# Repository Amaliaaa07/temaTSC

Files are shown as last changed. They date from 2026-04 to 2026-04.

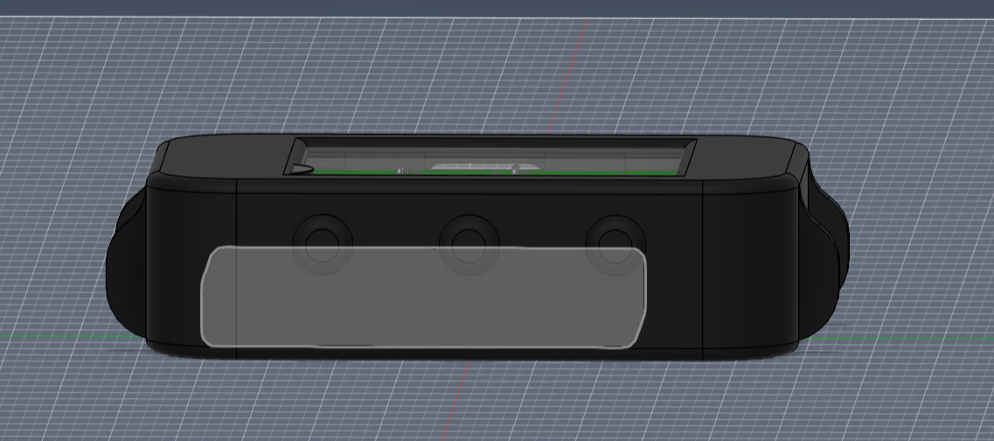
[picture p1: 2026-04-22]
Images/Screenshot 2026-04-22 074130.png

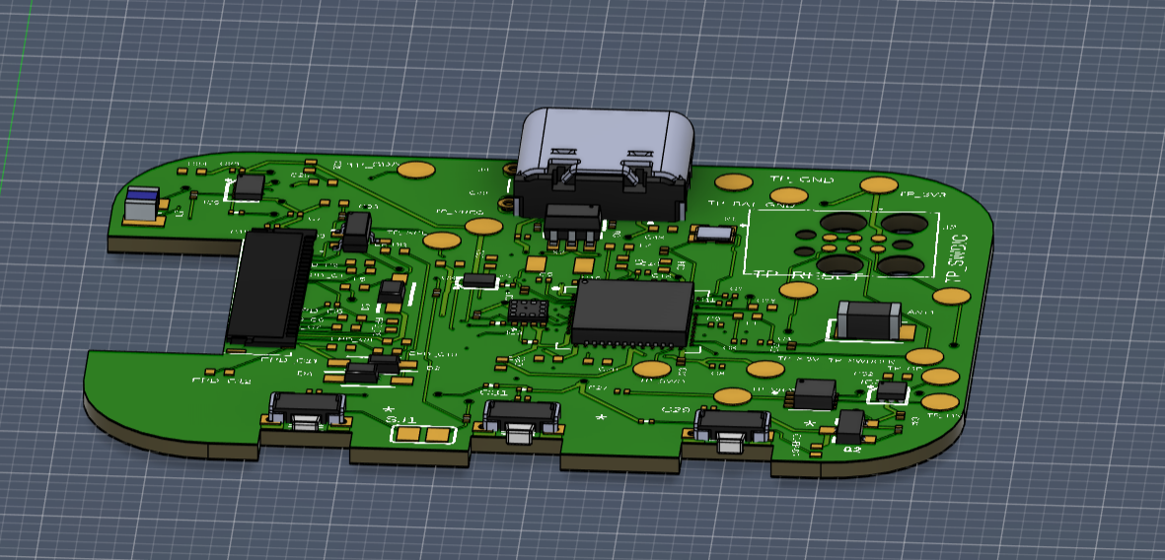
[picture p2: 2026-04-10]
Images/Screenshot 2026-04-10 213231.png

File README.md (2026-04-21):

# temaTSC
smartwatch


## BOM (Bill of Materials)

| Referință | Componentă | Descriere | Cantitate | Link JLC | Datasheet |
|---|---|---|---|---|---|
| U1 | MCU | nRF52840 | 1 | [JLC](https://jlcpcb.com/partdetail/NordicSemiconductor-nRF52840_QIAA/C190794) | [Datasheet](https://4donline.ihs.com/images/VipMasterIC/IC/NRSA/NRSA-S-A0021008244/NRSA-S-A0021008244-1.pdf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)  |
| IC1 | LiPo Charger | BQ25180YBGR | 1 | [JLC](https://componentsearchengine.com/prices/BQ25180YBGR?manufacturer=Texas%20Instruments) | [Datasheet](https://www.ti.com/lit/ds/symlink/bq25180.pdf) |
| IC2 | Haptic Driver | DRV2605YZFR | 1 | [JLC](https://componentsearchengine.com/prices/DRV2605YZFR?manufacturer=Texas%20Instruments) | [Datasheet](https://www.ti.com/lit/ds/symlink/drv2605.pdf) |
| IC3 | IMU | BMA423 | 1 | [JLC](https://componentsearchengine.com/prices/BMA423?manufacturer=BOSCH) | [Datasheet](https://4donline.ihs.com/images/VipMasterIC/IC/BSCH/BSCH-S-A0007921771/BSCH-S-A0010021471-1.pdf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) |
| IC9 | DC/DC Converter | RT6160AWSC | 1 | [JLC](https://componentsearchengine.com/prices/RT6160AWSC?manufacturer=RICHTEK) | [Datasheet](https://4donline.ihs.com/images/VipMasterIC/IC/RHTK/RHTK-S-A0025617216/RHTK-S-A0025617221-1.pdf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) |
| U3 | Fuel Gauge | MAX17048G+T10 | 1 | [JLC](https://componentsearchengine.com/prices/MAX17048G%2BT10?manufacturer=Analog%20Devices) | [Datasheet](https://4donline.ihs.com/images/VipMasterIC/IC/RHTK/RHTK-S-A0025617216/RHTK-S-A0025617221-1.pdf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) |
| D3 | ESD Protection  | USBLC6-2SC6Y | 1 | [JLC](https://componentsearchengine.com/prices/USBLC6-2SC6Y?manufacturer=STMicroelectronics) | [Datasheet](https://www.analog.com/media/en/technical-documentation/data-sheets/MAX17048-MAX17049.pdf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) |
| J4 | USB-C Connector | KH-TYPE-C-16P | 1 | [JLC](https://www.snapeda.com/parts/KH-TYPE-C-16P/kinghelm/view-part/?ref=search&t=KH-TYPE-C-16P&ab_test_case=b) | [Datasheet](https://www.snapeda.com/parts/KH-TYPE-C-16P/kinghelm/datasheet/) |
| J1 | E-Paper Connector | 503480-2400E | 1 | [JLC](https://componentsearchengine.com/prices/5034802400?manufacturer=Molex) | [Datasheet](https://4donline.ihs.com/images/VipMasterIC/IC/MOLE/MOLE-S-A0003522481/MOLE-S-A0010982248-1.pdf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) |
| ANT1 | Antena BLE | 2450AT18B100E | 1 | [JLC](https://componentsearchengine.com/prices/2450AT18B100E?manufacturer=JOHANSON%20TECHNOLOGY) | [Datasheet](https://www.johansontechnology.com/docs/1187/2450AT18B100_X8XXogU.pdf) |
| X1 | Crystal 32MHz | SMD 2016 | 1 | [JLC](https://componentsearchengine.com/prices/SMD2016B050TF?manufacturer=Yageo%20Group) | [Datasheet](https://4donline.ihs.com/images/VipMasterIC/IC/YAGO/YAGO-S-A0024580626/YAGO-S-A0024591343-1.pdf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) |
| X2 | Crystal 32.768kHz | SMD 2016 | 1 | [JLC](https://componentsearchengine.com/prices/SMD2016B050TF?manufacturer=Yageo%20Group) | [Datasheet](https://4donline.ihs.com/images/VipMasterIC/IC/YAGO/YAGO-S-A0024580626/YAGO-S-A0024591343-1.pdf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) |
| SW1-3 | Buton tactil | EVP-AKE31A | 3 | [JLC](https://componentsearchengine.com/prices/EVP-AKE31A?manufacturer=Panasonic) | [Datasheet](https://industrial.panasonic.com/cdbs/www-data/pdf/ATK0000/ATK0000C434.pdf) |
| J2 | SWD Connector | TC2030-IDC | 1 | [JLC](https://componentsearchengine.com/prices/TC2030-IDC?manufacturer=Tag%20Connect) | [Datasheet](https://4donline.ihs.com/images/VipMasterIC/IC/TGCN/TGCN-S-A0008988129/TGCN-S-A0008988129-1.pdf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) |
| Q2 | MOSFET P-ch | DMG2305UX-7 | 1 | [JLC](https://componentsearchengine.com/prices/DMG2305UX-7?manufacturer=Diodes%20Incorporated) | [Datasheet](https://4donline.ihs.com/images/VipMasterIC/IC/DIOD/DIOD-S-A0013043571/DIOD-S-A0013120650-1.pdf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) |
| Q3 | MOSFET N-ch | SI1308EDL-T1-GE3 | 1 | [JLC](https://componentsearchengine.com/prices/Si1308EDL-T1-GE3?manufacturer=Vishay) | [Datasheet](https://4donline.ihs.com/images/VipMasterIC/IC/VISH/VISH-S-A0000692786/VISH-S-A0000692786-1.pdf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) |
| D2, D4, D5  | Dioda Schottky  | MBR0530 | 3 | [JLC](https://componentsearchengine.com/prices/MBR0530?manufacturer=MCC) | [Datasheet](https://4donline.ihs.com/images/VipMasterIC/IC/MCCC/MCCCS04194/MCCCS04194-1.pdf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) |
| L1 | Inductanta 0.47µH | FTC252012SR47MBCA | 1 | [JLC](https://jlcpcb.com/partdetail/6763488-FTC252012SR47MBCA/C5832368) |
| L2 | Inductanta 15nH | RF matching 0201 | 1 | [JLC](https://jlcpcb.com/partdetail/Sunlord-SDCL0201C15NJTDF/C389547) | - |
| L3 | Inductanta 3.9nH | RF matching 0201 | 1 | [JLC](https://jlcpcb.com/partdetail/Sunlord-SDCL0201C3N9STDF/C389544) | - |
| L5 | Inductanta 68µH | EPD driver SMD | 1 | [JLC](https://jlcpcb.com/partdetail/Sumida-CDMC4D28NP680MC/C408336) | - |
| L7 | Inductanta 10µH | DC/DC SMD | 1 | [JLC](https://jlcpcb.com/partdetail/Sunlord-MWSA0402S100MT/C408352) | - |
| C* | Condensatoare | 100nF decuplare 0201 | multiple  | [JLC](https://jlcpcb.com/partdetail/Samsung-CL03B104KO3NNNC/C15195) | - |
| C* | Condensatoare | >100nF bulk 0402 | multiple  | [JLC](https://jlcpcb.com/partdetail/Samsung-CL05A475KP5NRNC/C25771) | - |
| R* | Rezistente | Diverse valori 0201 | multiple  | [JLC](https://jlcpcb.com/partdetail/UNI-ROYAL-0201WAF1001T5E/C17513) | - |

## Descrierea funcționalității hardware

### Microcontroller — nRF52840

Inima dispozitivului este **Nordic nRF52840**, un SoC (System on Chip) cu procesor ARM Cortex-M4 la 64 MHz, cu unitate FPU, 1 MB Flash, 256 KB RAM și radio Bluetooth 5.0 integrat. Chipul operează la 3.3V și gestionează toate perifericele prin interfețele SPI, I2C și GPIO.

### Alimentare

Lanțul de alimentare funcționează astfel:
- **USB-C (KH-TYPE-C-16P)** furnizează VBUS (5V) prin conectorul de încărcare
- **USBLC6-2SC6Y** protejează liniile D+/D- împotriva descărcărilor electrostatice (ESD)
- **BQ25180YBGR** este charger-ul LiPo care încarcă bateria de 3.7V și comunică cu MCU-ul prin I2C pentru a raporta starea încărcării. Curentul maxim de încărcare este de 350mA.
- **MAX17048G+T10** este fuel gauge-ul care măsoară tensiunea bateriei și estimează starea de încărcare (SoC) prin algoritmul ModelGauge, comunicând prin I2C. Generează o întrerupere ALERT când bateria scade sub un prag configurat.
- **RT6160AWSC** este un convertor DC/DC boost care generează tensiunea de 3.3V necesară MCU-ului și perifericelor din tensiunea bateriei. Frecvența de comutare este de 1.5MHz, folosind inductanța L7 de 10µH.

### Display E-Paper

Display-ul e-paper se conectează prin conectorul FFC **503480-2400** (24 pini). Interfața de comunicație este **SPI** (MOSI, SCK) împreună cu semnale de control GPIO:
- **EPD_CS** — chip select
- **EPD_DC** — selectare mod Data/Command
- **EPD_RST** — reset display
- **EPD_BUSY** — semnal de ocupat (MCU-ul așteaptă să devină LOW înainte de a trimite date noi)

Circuitul de drive al display-ului conține diode Schottky MBR0530, MOSFET-uri și inductanța L5 (68µH) pentru generarea tensiunilor ridicate necesare panoului e-paper (PREVGH pozitiv, PREVGL negativ). Marele avantaj al display-ului e-paper este consumul zero în standby — imaginea rămâne afișată fără alimentare (display bistabil).

### IMU — BMA421

Senzorul de mișcare **BMA421** de la Bosch este un accelerometru 3-axis cu consum ultra-redus, folosit pentru:
- Detectarea pașilor (pedometru integrat în hardware)
- Recunoașterea activității (mers, alergat, stat)
- Detectarea orientării dispozitivului
- Wake-up la mișcare (trezirea MCU-ului din sleep)

Comunică cu MCU-ul prin **I2C** la adresa 0x18 sau 0x19 (selectabilă prin pinul SDO). Generează întreruperi pe liniile **INT1** și **INT2** pentru a trezi MCU-ul la detectarea unor evenimente, fără a consuma energie în modul standby. Tensiunea de alimentare este 3.3V (VDDIO și VDD).

### Driver Haptic — DRV2605YZFR

**DRV2605YZFR** de la Texas Instruments este un driver pentru actuatoare haptice (LRA/ERM) cu bibliotecă internă de 123 de efecte de vibrație stocate în ROM. Comunică prin **I2C** la adresa 0x5A și este activat de MCU prin semnalul **HAPTIC_EN** (GPIO). Oferă feedback tactil utilizatorului la interacțiunile cu interfața (notificări, confirmare butoane etc.).

### Conectivitate BLE

Radio-ul BLE integrat în nRF52840 operează la 2.4GHz și suportă Bluetooth 5.0 cu rate de date de 1Mbps (LE 1M PHY) și 2Mbps (LE 2M PHY). Este conectat la antena **2450AT18B100E** de la Johanson Technology printr-o rețea de matching RF compusă din L2 (15nH), L3 (3.9nH) și condensatoare de 1pF. Antena este plasată la exteriorul PCB-ului, iar zona de sub antenă este decupată complet (fără cupru și fără trasee) pentru a nu degrada performanța RF.

### Butoane

Trei butoane tactile **EVP-AKE31A** de la Panasonic (SW_UP, SW_DN, SW_ENT) sunt conectate la GPIO-urile MCU-ului cu rezistențe de pull-up de 10kΩ. La apăsare, pinul GPIO este tras la GND. Butoanele sunt plasate pe marginea PCB-ului, aliniate cu orificiile fizice din carcasă.

### Debug SWD

Interfața de programare și depanare **SWD** este expusă prin conectorul **TC2030-IDC** (Tag-Connect 6-pin, fără găuri). Semnalele disponibile sunt SWDIO, SWDCLK, SWO (trace), RESET, 3.3V și GND. Toate sunt marcate pe silkscreen cu test pad-uri dedicate.

### Oscilatoare

- **Crystal 32 MHz** — oscilator principal pentru MCU și radio BLE, cu condensatoare de sarcină de 12pF. Conectat pe pinii dedicați P0.00/XL1 și P0.01/XL2.
- **Crystal 32.768 kHz** — oscilator pentru RTC (Real Time Clock), cu condensatoare de 12pF. Conectat pe pinii dedicați XC1 și XC2. Permite timekeeping precis în modul low power.

---

## Calcul consum de energie

| Componentă | Curent tipic | Mod |
|---|---|-----|
| nRF52840 | 4.8 mA | Activ CPU |
| nRF52840 | 0.4 µA | Deep sleep |
| nRF52840 | 5.3 mA | BLE advertising |
| BMA421 | 150 µA | Normal |
| BMA421 | 2 µA | Low power |
| DRV2605 | 9 mA | Activ |
| DRV2605 | 40 µA | Standby |
| MAX17048 | 23 µA | Activ |
| RT6160AWSC | ~50 µA | Quiescent |
| Display e-paper | ~26 mA | Refresh |
| Display e-paper | 0 mA | Standby (bistabil) |

**Estimare autonomie:** Cu o baterie LiPo de 200mAh, în modul normal de utilizare (MCU în sleep majoritatea timpului, refresh display de câteva ori pe zi, BLE advertising periodic), curentul mediu estimat este de aproximativ 1-2mA, rezultând o autonomie de **4-8 zile**.

## Pinii nRF52840 utilizați

| Pin nRF52840 | Semnal | Componentă | Interfață | Motiv |
|---|---|---|---|---|
| P0.00/XL1 | XL1 | Crystal 32MHz | XTAL | Pin dedicat oscilator principal |
| P0.01/XL2 | XL2 | Crystal 32MHz | XTAL | Pin dedicat oscilator principal |
| XC1, XC2 | - | Crystal 32.768kHz | XTAL | Pini RTC dedicați |
| P0.04 | EPD_CS | E-Paper | SPI CS | Chip select display |
| P0.05 | EPD_DC | E-Paper | GPIO | Data/Command select |
| P0.06 | MOSI | E-Paper | SPI | Date SPI |
| P0.07 | SCK | E-Paper | SPI | Clock SPI |
| P0.08 | EPD_RST | E-Paper | GPIO | Reset display |
| P0.09 | EPD_BUSY | E-Paper | GPIO | Busy signal display |
| P0.13 | D- | USB-C | USB | Linie date USB |
| P0.14 | D+ | USB-C | USB | Linie date USB |
| P0.25 | SDA | I2C bus | I2C | Date I2C (IMU, Haptic, Charger, FuelGauge) |
| P0.26 | SCL | I2C bus | I2C | Clock I2C |
| P0.27 | PMIC_INT | BQ25180 | GPIO | Întrerupere charger |
| P0.28 | ALERT | MAX17048 | GPIO | Alertă fuel gauge |
| P1.01 | HAPTIC_EN | DRV2605 | GPIO | Enable driver haptic |
| P1.02 | IMU_INT1 | BMA421 | GPIO | Întrerupere IMU 1 |
| P1.03 | IMU_INT2 | BMA421 | GPIO | Întrerupere IMU 2 |
| P1.04 | SW_UP | Buton UP | GPIO | Buton sus |
| P1.05 | SW_DN | Buton DOWN | GPIO | Buton jos |
| P1.06 | SW_ENT | Buton ENTER | GPIO | Buton enter |
| P0.18/RESET | RESET | SWD | SWD | Reset MCU |
| SWDCLK | SWDCLK | TC2030-IDC | SWD | Clock debug |
| SWDIO | SWDIO | TC2030-IDC | SWD | Date debug |
| P0.22 | SWO | TC2030-IDC | SWD | Trace output |
| ANT | RF | Antenă BLE | RF | Pin antenă dedicat |
| VBUS | VBUS | USB-C | Power | Detecție VBUS |

---

## Design log

### Probleme întâmpinate și decizii luate

**Erori Overlap (12) — Aprobate**: Cele 12 erori de overlap 
sunt de trei tipuri:

**Via-Smd Overlap (2)**: Via-uri care se suprapun ușor 
  cu pad-uri SMD în zone aglomerate ale PCB-ului. Mutarea 
  acestora ar compromite rutarea semnalelor din zonă.

**Solid Polygon Shape-Pad Overlap (2)**: Pad-ul 
  termal al unui circuit integrat se suprapune ușor 
  cu conturul (courtyard) componentei vecine. 
  Suprapunerea este minimă și nu afectează 
  funcționalitatea electrică sau asamblarea, 
  deoarece componentele nu se suprapun fizic.

**Smd-Via Overlap (6)**: Via-uri plasate în apropierea 
  pad-urilor SMD în zone aglomerate ale PCB-ului. Acestea 
  sunt necesare pentru rutarea semnalelor și nu pot fi 
  mutate fără a compromite rutarea generală. Suprapunerea 
  este minimă și nu afectează funcționalitatea electrică 
  sau procesul de fabricație.

**Modelele 3D**
Componentele mici (rezistențe 0201, condensatoare 0201/0402) nu au modele 3D individuale asociate și folosesc modelul generic din Fusion 360. Componentele principale (nRF52840, BQ25180, conectorul USB-C, butoanele, cristalele) au modele 3D reale asociate.

---

## Imagini

Randările PCB-ului și ale dispozitivului complet se găsesc în folderul `/Images`.

---

## Licență

Acest proiect este licențiat sub licența **Apache 2.0**. Vezi fișierul [LICENSE](LICENSE) pentru detalii.

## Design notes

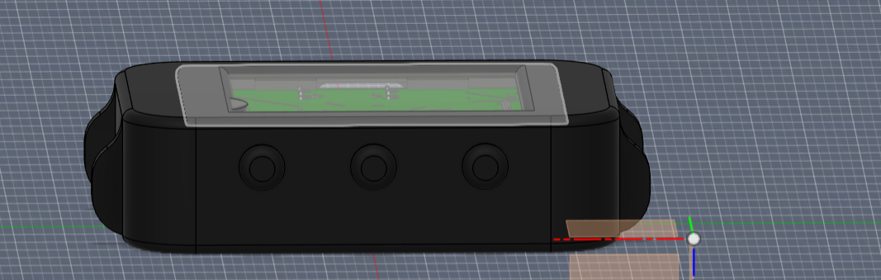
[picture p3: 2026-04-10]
Images/Screenshot 2026-04-10 212922.png

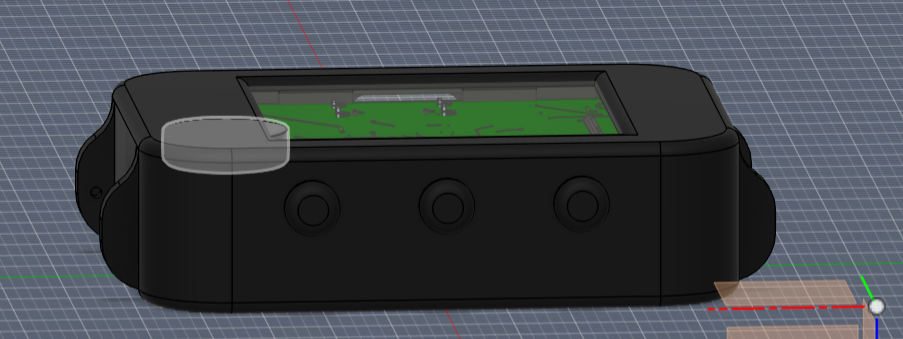
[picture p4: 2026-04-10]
Images/Screenshot 2026-04-10 212859.png

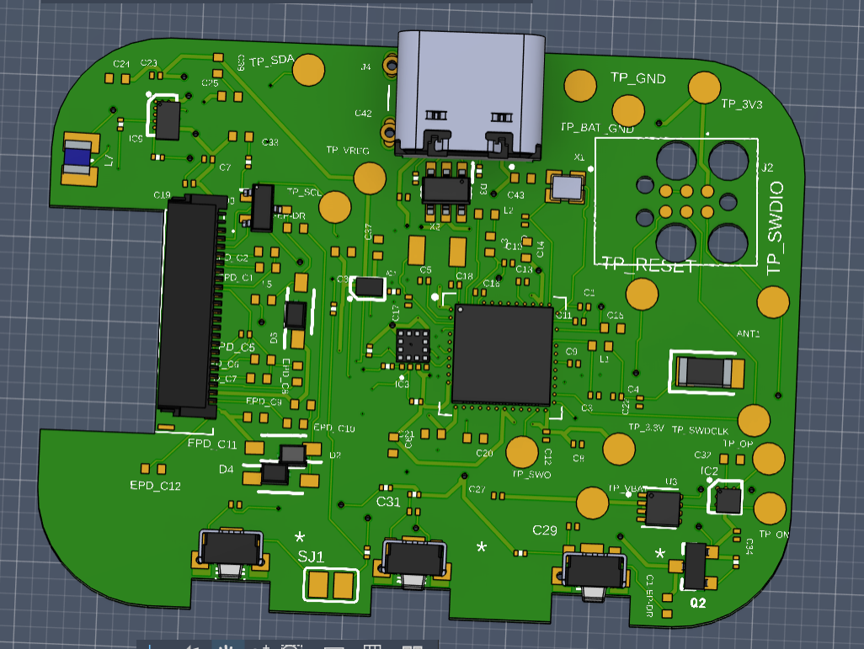
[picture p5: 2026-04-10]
Images/Screenshot 2026-04-10 213246.png

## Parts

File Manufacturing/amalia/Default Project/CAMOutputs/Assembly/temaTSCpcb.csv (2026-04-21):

Qty | Value | Device | Package | Parts | Description | ARROW_PART_NUMBER | ARROW_PRICE-STOCK | AVAILABILITY | CHECK_PRICES | COPYRIGHT | DESCRIPTION | DIGI-KEY_PART_NUMBER_1 | DIGI-KEY_PART_NUMBER_2 | DIGI-KEY_PART_NUMBER_3 | HEIGHT | JLCPCB | MANUFACTURER_NAME | MANUFACTURER_PART_NUMBER | MF | MOUSER_PART_NUMBER | MOUSER_PRICE-STOCK | MP | PACKAGE | POPULARITY | PRICE | PROD_ID | PURCHASE-URL | SNAPEDA_LINK | TP_SIGNAL_NAME | VALUE
1 |  | ESP32_C6_LIBRARY_7_JUMPER_SJ | ESP32_C6_LIBRARY_7_JUMPER_SJ | SJ1 | SMD solder JUMPER |  |  |  |  |  |  |  |  |  |  |  |  |  |  |  |  |  |  | 3
3 | 0 | ERA-1AEB3401C_CPF0201D7K68C1 | ERA-1AEB3401C_0201 | R2, R3, R4 | 7.68k 0201 Thin Film Surface Mount Fixed Resistor +/-0.5% 0.031W CPF0201D7K68C1
2 | 0.1uF | GRM011R60J152KE01L_1_GRM011R60J152KE01L | GRM011R60J152KE01L_1_0201 | C26, C34 | Check availability
2 | 0.1uF | NORDIC_NRF_3_CAPACITOR_0201_L | NORDIC_NRF_3_RESC0201_L | C23, C42 | Generic chip capacitor
1 | 0.1uF/50V | NORDIC_NRF_3_CAPACITOR_0201_L | NORDIC_NRF_3_RESC0201_L | EPD_C5 | Generic chip capacitor
1 | 0.47 | ERA-1AEB3401C_CPF0201D7K68C1 | ERA-1AEB3401C_0201 | R1_EP_DR | 7.68k 0201 Thin Film Surface Mount Fixed Resistor +/-0.5% 0.031W CPF0201D7K68C1
1 | 1.0uF | NORDIC_NRF_3_CAPACITOR_0402_L | NORDIC_NRF_3_RESC0402_L | C15 | Generic chip capacitor
5 | 100nF | NORDIC_NRF_3_CAPACITOR_0201_L | NORDIC_NRF_3_RESC0201_L | C5, C7, C8, C12, C19 | Generic chip capacitor
1 | 100pF | NORDIC_NRF_3_CAPACITOR_0201_L | NORDIC_NRF_3_RESC0201_L | C11 | Generic chip capacitor
6 | 10K | ERA-1AEB3401C_CPF0201D7K68C1 | ERA-1AEB3401C_0201 | R2_EP_DR, R5, R7, R8, R9, R_PWR_EPD | 7.68k 0201 Thin Film Surface Mount Fixed Resistor +/-0.5% 0.031W CPF0201D7K68C1
3 | 10uF | NORDIC_NRF_3_CAPACITOR_0402_L | NORDIC_NRF_3_RESC0402_L | C1-EP-DR, C24, C39 | Generic chip capacitor
1 | 10uH | NORDIC_NRF_2_INDUCTOR_0402_L | NORDIC_NRF_2_RESC0402_L | L2 | Generic chip inductor
4 | 12pF | NORDIC_NRF_3_CAPACITOR_0201_L | NORDIC_NRF_3_RESC0201_L | C1, C2, C17, C18 | Generic chip capacitor
1 | 15uH | NORDIC_NRF_2_INDUCTOR_0402_L | NORDIC_NRF_2_RESC0402_L | L3 | Generic chip inductor
2 | 1pF | NORDIC_NRF_3_CAPACITOR_0201_L | NORDIC_NRF_3_RESC0201_L | C3, C4 | Generic chip capacitor
4 | 1uF | GRM011R60J152KE01L_1_GRM011R60J152KE01L | GRM011R60J152KE01L_1_0201 | C29, C30, C31, C32 | Check availability
2 | 1uF | NORDIC_NRF_3_CAPACITOR_0402_L | NORDIC_NRF_3_RESC0402_L | C37, C38 | Generic chip capacitor
9 | 1uF/50V | NORDIC_NRF_3_CAPACITOR_0402_L | NORDIC_NRF_3_RESC0402_L | EPD_C1, EPD_C2, EPD_C6, EPD_C7, EPD_C8, EPD_C9, EPD_C10, EPD_C11, EPD_C12 | Generic chip capacitor
1 | 2.2 | ERA-1AEB3401C_CPF0201D7K68C1 | ERA-1AEB3401C_0201 | R_TYPE_SEL | 7.68k 0201 Thin Film Surface Mount Fixed Resistor +/-0.5% 0.031W CPF0201D7K68C1
3 | 2025-10-22_07-23-44_LIBRARY_EVP-AKE31ASW_EVP-AKE31A_PAN | 2025-10-22_07-23-44_LIBRARY_EVP-AKE31ASW_EVP-AKE31A_PAN | 2025-10-22_07-23-44_LIBRARY_SW_EVP-AKE31A_PAN | SW_DN, SW_ENT, SW_UP |  |  |  |  |  | Copyright (C) 2025 Ultra Librarian. All rights reserved. |  | P123437TR-ND | P123437CT-ND | P123437DKR-ND |  |  | Panasonic | EVP-AKE31A
1 | 20V/4.2A/52mO/1.4W | ESP32_C6_LIBRARY_4_ESP32_WROVER_SPARKFUN-DISCRETESEMI_MOSFET_PCH-DMG2305UX-7 | ESP32_C6_LIBRARY_4_ESP32_C6_LIBRARY_4_ESP32_C6_LIBRARY_4_ESP32_C6_LIBRARY_4_ESP32_WROVER_SPARKFUN-DISCRETESEMI_SOT23-3 | Q1 | P-channel MOSFETs |  |  |  |  |  |  |  |  |  |  |  |  |  |  |  |  |  |  |  |  | TRAN-14388 |  |  |  | 20V/4.2A/52mO/1.4W
2 | 22uF | NORDIC_NRF_3_CAPACITOR_0402_L | NORDIC_NRF_3_RESC0402_L | C25, C33 | Generic chip capacitor
1 | 2450AT18B100E_2450AT18B100E | 2450AT18B100E_2450AT18B100E | 2450AT18B100E_ANTC3216X140N | ANT1 | Antennas 2.45GHz ANTENNA | 2450AT18B100E | https://www.arrow.com/en/products/2450at18b100e/johanson-dielectrics?utm_currency=USD&region=nac |  |  |  | Antennas 2.45GHz ANTENNA |  |  |  | 1.4mm |  | JOHANSON TECHNOLOGY | 2450AT18B100E |  | 609-2450AT18B100E | https://www.mouser.co.uk/ProductDetail/Johanson-Technology/2450AT18B100E?qs=yCnrNFeXz%252Bh5MFsFIXGZGA%3D%3D
1 | 3.9nH | NORDIC_NRF_2_INDUCTOR_0402_L | NORDIC_NRF_2_RESC0402_L | L1 | Generic chip inductor
1 | 32.768kHz | NORDIC_NRF_1_XTAL_32KHZ | NORDIC_NRF_1_XTAL_3215_N | X2
1 | 32MHz | NORDIC_NRF_XTAL_32MHZ | NORDIC_NRF_BT-XTAL_2016_N | X1
1 | 3K3 | ERA-1AEB3401C_CPF0201D7K68C1 | ERA-1AEB3401C_0201 | R17 | 7.68k 0201 Thin Film Surface Mount Fixed Resistor +/-0.5% 0.031W CPF0201D7K68C1
1 | 3k3 | ERA-1AEB3401C_CPF0201D7K68C1 | ERA-1AEB3401C_0201 | R18 | 7.68k 0201 Thin Film Surface Mount Fixed Resistor +/-0.5% 0.031W CPF0201D7K68C1
5 | 4.7uF | NORDIC_NRF_3_CAPACITOR_0402_L | NORDIC_NRF_3_RESC0402_L | C6, C14, C20, C21, C43 | Generic chip capacitor
1 | 4.7uF/25V | NORDIC_NRF_3_CAPACITOR_0402_L | NORDIC_NRF_3_RESC0402_L | C2-EP-DR | Generic chip capacitor
1 | 47nF | NORDIC_NRF_3_CAPACITOR_0201_L | NORDIC_NRF_3_RESC0201_L | C16 | Generic chip capacitor
1 | 503480-2400_503480-2400 | 503480-2400_503480-2400 | 503480-2400_5034802400 | J1 | FFC & FPC Connectors 0.5mm FPC RA SMT Dual Contact 24Ckt |  |  |  |  |  | FFC & FPC Connectors 0.5mm FPC RA SMT Dual Contact 24Ckt |  |  |  | 1.87mm |  | Molex | 503480-2400 |  | 538-503480-2400 | https://www.mouser.co.uk/ProductDetail/Molex/503480-2400?qs=OAhjpuo3Vu7efIoxFh9AOw%3D%3D
2 | 5K1 | ERA-1AEB3401C_CPF0201D7K68C1 | ERA-1AEB3401C_0201 | R1_USB, R2_USB | 7.68k 0201 Thin Film Surface Mount Fixed Resistor +/-0.5% 0.031W CPF0201D7K68C1
1 | 68uH | NORDIC_NRF_2_INDUCTOR_0402_L | NORDIC_NRF_2_RESC0402_L | L5 | Generic chip inductor
1 | 820pF | NORDIC_NRF_3_CAPACITOR_0201_L | NORDIC_NRF_3_RESC0201_L | C9 | Generic chip capacitor
1 | BMA423_BMA423 | BMA423_BMA423 | BMA423_BMA423 | IC3 | Accelerometers Triaxial low-g 12bit Acceleration Sensor | BMA423 | https://www.arrow.com/en/products/bma423/bosch |  |  |  | Accelerometers Triaxial low-g 12bit Acceleration Sensor |  |  |  | 1mm |  | BOSCH | BMA423 |  | 262-BMA423 | https://www.mouser.co.uk/ProductDetail/Bosch-Sensortec/BMA423?qs=HXFqYaX1Q2xC%252BSgeGoX3mg%3D%3D
1 | BQ25180YBGR_BQ25180YBGR | BQ25180YBGR_BQ25180YBGR | BQ25180YBGR_BGA8C40P2X4_100X155X50 | IC1 | Charger IC Lithium Ion/Polymer, Lithium Iron Phosphate 8-DSBGA (1.6x1.1) | BQ25180YBGR | https://www.arrow.com/en/products/bq25180ybgr/texas-instruments?utm_currency=USD&region=nac |  |  |  | Charger IC Lithium Ion/Polymer | Lithium Iron Phosphate 8-DSBGA (1.6x1.1) |  |  |  | 0.5mm |  | Texas Instruments | BQ25180YBGR |  | 595-BQ25180YBGR | https://www.mouser.co.uk/ProductDetail/Texas-Instruments/BQ25180YBGR?qs=doiCPypUmgEWjAK%252BJAX6Tw%3D%3D
1 | DRV2605YZFR_DRV2605YZFR | DRV2605YZFR_DRV2605YZFR | DRV2605YZFR_BGA9C50P3X3_144X144X62 | IC2 | Haptic Driver for ERM/LRA with Built-In Library and Smart Loop Architecture | DRV2605YZFR | https://www.arrow.com/en/products/drv2605yzfr/texas-instruments?region=nac |  |  |  | Haptic Driver for ERM/LRA with Built-In Library and Smart Loop Architecture |  |  |  | 0.625mm |  | Texas Instruments | DRV2605YZFR
1 | ESP32_C6_LIBRARY_3_USBLC6-2SC6Y | ESP32_C6_LIBRARY_3_USBLC6-2SC6Y | ESP32_C6_LIBRARY_3_SOT95P280X145-6N | D3 | Low Cap. ESD Protection Auto SOT-23-6 STMicroelectronics USBLC6-2SC6Y, Dual Uni-Directional TVS Diode Array, 6-Pin SOT-23 |  |  | In Stock | https://www.snapeda.com/parts/USBLC6-2SC6Y/STMicroelectronics/view-part/?ref=eda |  | 17V Clamp 5A (8/20µs) Ipp Tvs Diode Surface Mount SOT-23-6 |  |  |  |  |  |  |  | STMicroelectronics |  |  | USBLC6-2SC6Y | SOT-23-6 STMicroelectronics |  | None |  |  | https://www.snapeda.com/parts/USBLC6-2SC6Y/STMicroelectronics/view-part/?ref=snap
3 | ESP32_C6_LIBRARY_5_MBR0530 | ESP32_C6_LIBRARY_5_MBR0530 | ESP32_C6_LIBRARY_5_SOD3716X135N | D2, D4, D5 | ON SEMICONDUCTOR - MBR0530 - DIODE, SCHOTTKY, 0.5A, 30V, SOD-123 |  |  | In Stock | https://www.snapeda.com/parts/MBR0530/Onsemi/view-part/?ref=eda |  | Diode Schottky 30 V 500mA Surface Mount SOD-123 |  |  |  |  |  |  |  | ON Semiconductor |  |  | MBR0530 | SOD-123-2 ON Semiconductor |  | None |  | https://www.snapeda.com/api/url_track_click_mouser/?unipart_id=179458&manufacturer=ON Semiconductor&part_name=MBR0530&search_term=None | https://www.snapeda.com/parts/MBR0530/Onsemi/view-part/?ref=snap
1 | ESP32_C6_LIBRARY_6_SI1308EDL-T1-GE3 | ESP32_C6_LIBRARY_6_SI1308EDL-T1-GE3 | ESP32_C6_LIBRARY_6_SOT65P210X110-3N | Q3 | MOSFET N-Ch 30V 1.5A TrenchFET SC70 Vishay Si1308EDL-T1-GE3 N-channel MOSFET Transistor, 1.5 A, 30 V, 3-Pin SC-70 |  |  | In Stock | https://www.snapeda.com/parts/SI1308EDL-T1-GE3/Vishay+Siliconix/view-part/?ref=eda |  | Si1308EDL-T1-GE3 N-channel MOSFET Transistor | 1.5 A | 30 V | 3-Pin SC-70 | Siliconix / Vishay SI1308EDL-T1-GE3 |  |  |  |  |  |  |  | Vishay Siliconix |  |  | SI1308EDL-T1-GE3 | SOT-323 Vishay Semiconductor |  | None |  | https://www.snapeda.com/api/url_track_click_mouser/?unipart_id=274603&manufacturer=Vishay Siliconix&part_name=SI1308EDL-T1-GE3&search_term=None
1 | ESP32_C6_LIBRARY_MAX17048G+T10 | ESP32_C6_LIBRARY_MAX17048G+T10 | ESP32_C6_LIBRARY_SON50P200X200X80-9N | U3 | Check availability |  |  | In Stock | https://www.snapeda.com/parts/MAX17048G+T10/Analog+Devices/view-part/?ref=eda |  | 3µA 1-Cell/2-Cell Fuel Gauge with ModelGauge |  |  |  |  |  |  |  | Analog Devices |  |  | MAX17048G+T10 | TDFN-8 Maxim |  | None |  | https://www.snapeda.com/api/url_track_click_mouser/?unipart_id=329239&manufacturer=Analog Devices&part_name=MAX17048G+T10&search_term=None | https://www.snapeda.com/parts/MAX17048G+T10/Analog+Devices/view-part/?ref=snap
14 | HECTOR_WATCH_1_TPTP20R | HECTOR_WATCH_1_TPTP20R | HECTOR_WATCH_1_TP20R | TP_3.3V, TP_3V3, TP_BAT_GND, TP_GND, TP_ON, TP_OP, TP_RESET, TP_SCL, TP_SDA, TP_SWDCLK, TP_SWDIO, TP_SWO, TP_VBAT, TP_VREG | Test pad |  |  |  |  |  |  |  |  |  |  |  |  |  |  |  |  |  |  | 2
1 | KH-TYPE-C-16P_KH-TYPE-C-16P | KH-TYPE-C-16P_KH-TYPE-C-16P | KH-TYPE-C-16P_KINGHELM_KH-TYPE-C-16P | J4 | Check availability |  |  | Not in stock | https://www.snapeda.com/parts/KH-TYPE-C-16P/Kinghelm/view-part/?ref=eda |  |  |  |  |  |  |  |  |  | kinghelm |  |  | KH-TYPE-C-16P | None |  | None |  |  | https://www.snapeda.com/parts/KH-TYPE-C-16P/Kinghelm/view-part/?ref=snap
1 | MLP2016SR47MT0S1_FTC252012SR47MBCA | MLP2016SR47MT0S1_FTC252012SR47MBCA | MLP2016SR47MT0S1_INDC2016X100N | L7 | SMD / SMT Inductors (Coils), L=0.47?H, L x W x T : |  |  |  |  |  | SMD / SMT Inductors (Coils) | L=0.47?H | L x W x T : |  |  |  | 1mm | https://jlcpcb.com/partdetail/6763488-FTC252012SR47MBCA/C5832368 | TDK | FTC252012SR47MBCA
3 | N.C. | NORDIC_NRF_3_CAPACITOR_0201_L | NORDIC_NRF_3_RESC0201_L | C10, C13, C22 | Generic chip capacitor
1 | NRF52840_QF | NORDIC_NRF_4_NRF52840_QF | NORDIC_NRF_4_AQFN50P700X700X85_HS-74N | U1 | nRF52840
1 | RT6160AWSC_RT6160AWSC | RT6160AWSC_RT6160AWSC | RT6160AWSC_BGA15C40P3X5_140X230X60 | IC9 | Buck-Boost Regulator Positive Output Step-Up/Step-Down I2C DC-DC Controller IC 15-WL-CSP (BSC) (1.4x2.3) |  |  |  |  |  | Buck-Boost Regulator Positive Output Step-Up/Step-Down I2C DC-DC Controller IC 15-WL-CSP (BSC) (1.4x2.3) |  |  |  | 0.6mm |  | RICHTEK | RT6160AWSC |  | 835-RT6160AWSC | https://www.mouser.co.uk/ProductDetail/Richtek/RT6160AWSC?qs=amGC7iS6iy%2FLd9PSoixZXQ%3D%3D
1 | TC2030-IDC_TC2030-IDC | TC2030-IDC_TC2030-IDC | TC2030-IDC_TC2030IDC | J2 | CABLE ADAPTER 6 POS |  |  |  |  |  | CABLE ADAPTER 6 POS |  |  |  | 19mm |  | Tag Connect | TC2030-IDC

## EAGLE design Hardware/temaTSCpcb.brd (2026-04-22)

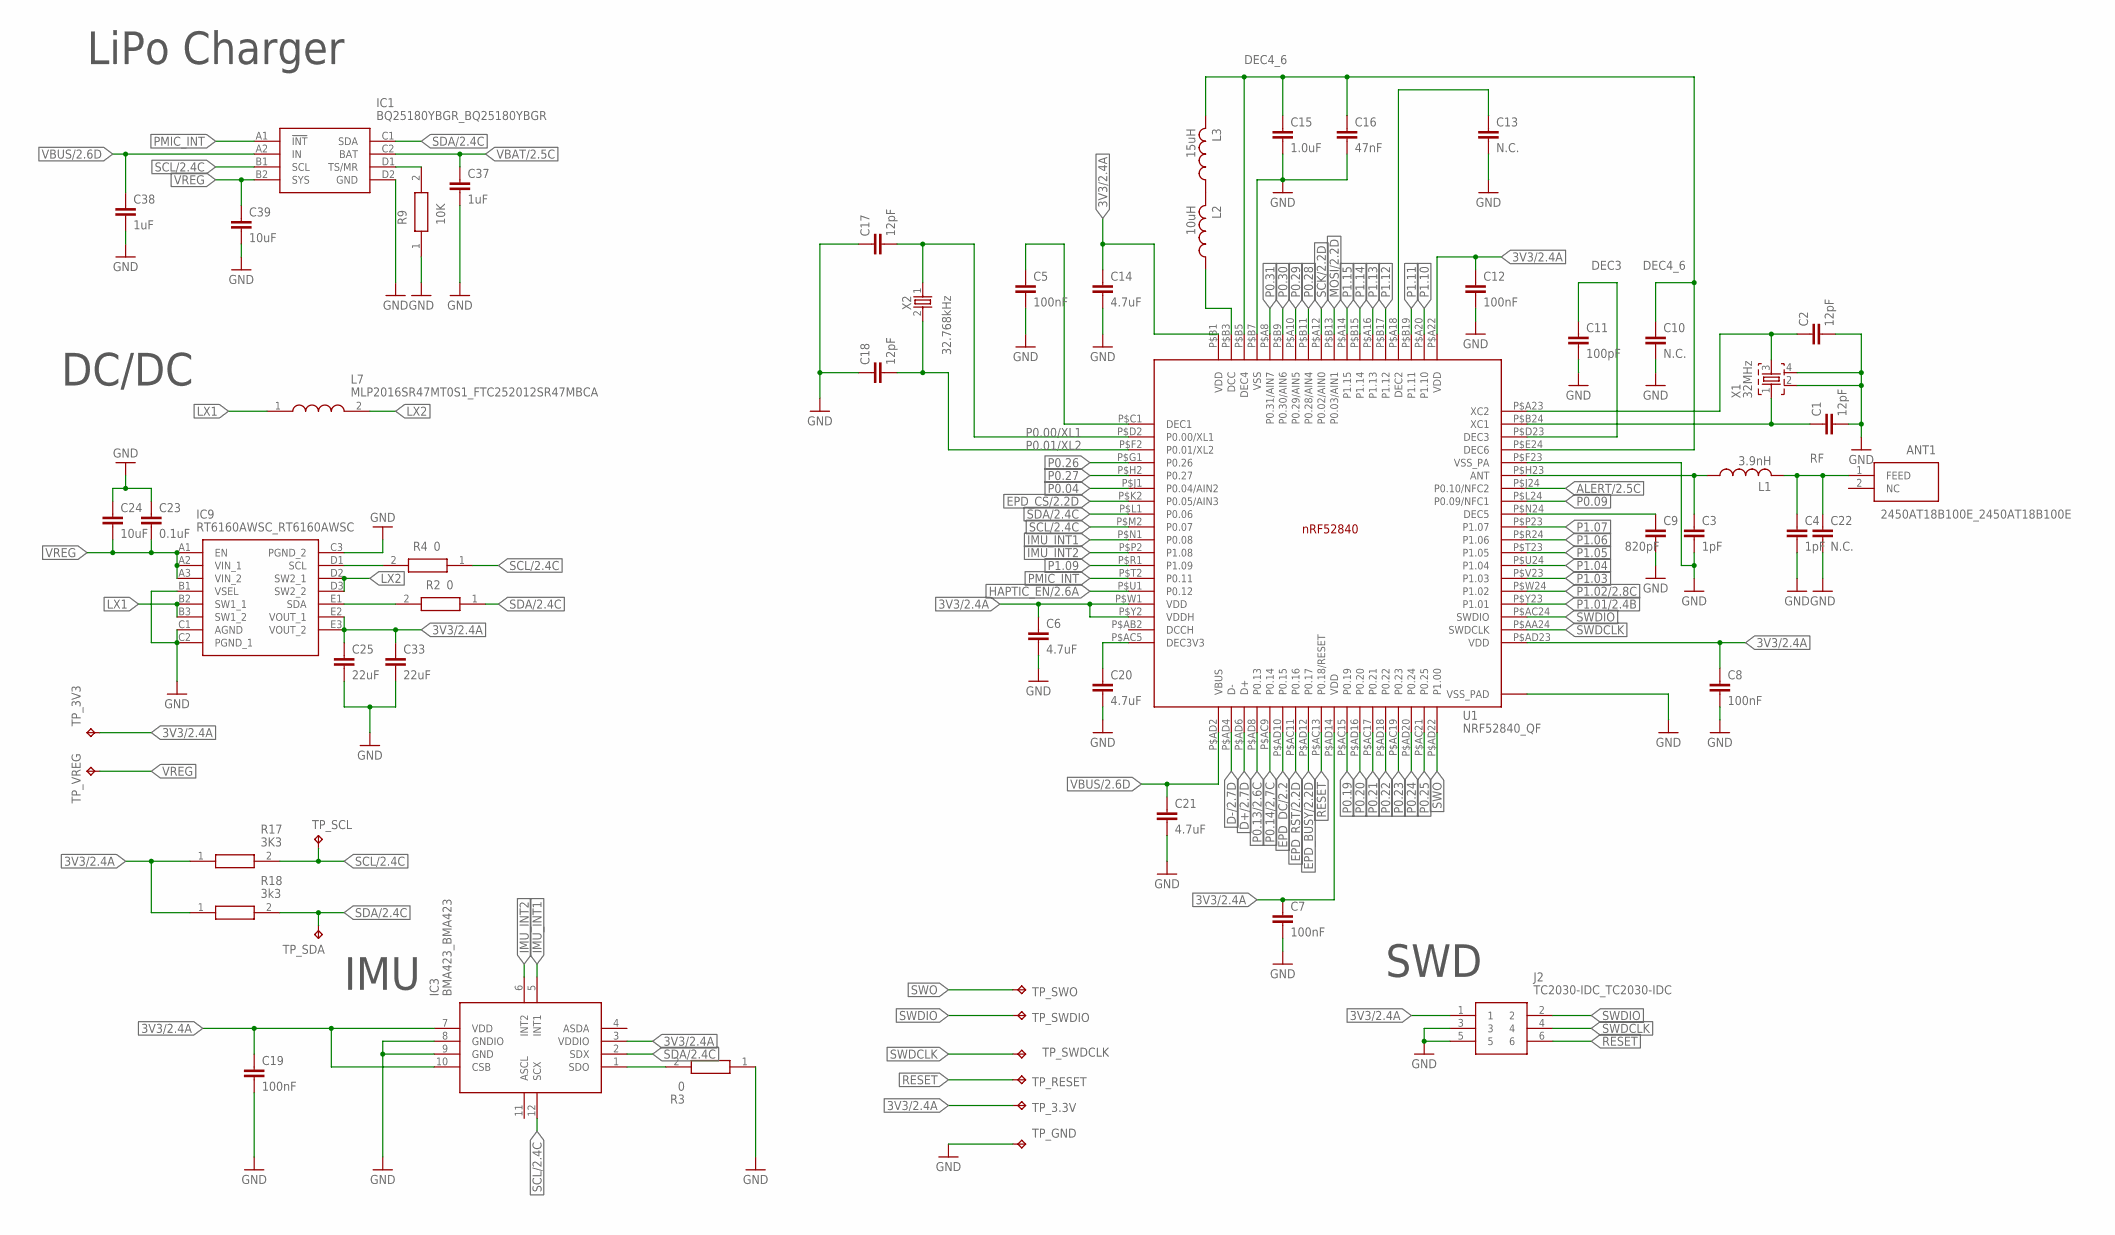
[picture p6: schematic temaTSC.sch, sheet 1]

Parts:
ANT1: 2450AT18B100E_2450AT18B100E; 2450AT18B100E_ANTC3216X140N
C1, C2, C17, C18: 12pF; NORDIC_NRF_3_RESC0201_L
C3, C4: 1pF; NORDIC_NRF_3_RESC0201_L
C5, C7, C8, C12, C19: 100nF; NORDIC_NRF_3_RESC0201_L
C6, C14, C20, C21: 4.7uF; NORDIC_NRF_3_RESC0402_L
C9: 820pF; NORDIC_NRF_3_RESC0201_L
C10, C13, C22: N.C.; NORDIC_NRF_3_RESC0201_L
C11: 100pF; NORDIC_NRF_3_RESC0201_L
C15: 1.0uF; NORDIC_NRF_3_RESC0402_L
C16: 47nF; NORDIC_NRF_3_RESC0201_L
C23: 0.1uF; NORDIC_NRF_3_RESC0201_L
C24, C39: 10uF; NORDIC_NRF_3_RESC0402_L
C25, C33: 22uF; NORDIC_NRF_3_RESC0402_L
C37, C38: 1uF; NORDIC_NRF_3_RESC0402_L
IC1: BQ25180YBGR_BQ25180YBGR; BQ25180YBGR_BGA8C40P2X4_100X155X50
IC3: BMA423_BMA423
IC9: RT6160AWSC_RT6160AWSC; RT6160AWSC_BGA15C40P3X5_140X230X60
J2: TC2030-IDC_TC2030-IDC; TC2030-IDC_TC2030IDC
L1: 3.9nH; NORDIC_NRF_2_RESC0402_L
L2: 10uH; NORDIC_NRF_2_RESC0402_L
L3: 15uH; NORDIC_NRF_2_RESC0402_L
L7: MLP2016SR47MT0S1_FTC252012SR47MBCA; MLP2016SR47MT0S1_INDC2016X100N
R2, R3, R4: 0; ERA-1AEB3401C_0201
R9: 10K; ERA-1AEB3401C_0201
R17: 3K3; ERA-1AEB3401C_0201
R18: 3k3; ERA-1AEB3401C_0201
TP_3.3V, TP_3V3: HECTOR_WATCH_1_TPTP20R; HECTOR_WATCH_1_TP20R
TP_GND: HECTOR_WATCH_1_TPTP20R; HECTOR_WATCH_1_TP20R
TP_RESET: HECTOR_WATCH_1_TPTP20R; HECTOR_WATCH_1_TP20R
TP_SCL: HECTOR_WATCH_1_TPTP20R; HECTOR_WATCH_1_TP20R
TP_SDA: HECTOR_WATCH_1_TPTP20R; HECTOR_WATCH_1_TP20R
TP_SWDCLK: HECTOR_WATCH_1_TPTP20R; HECTOR_WATCH_1_TP20R
TP_SWDIO: HECTOR_WATCH_1_TPTP20R; HECTOR_WATCH_1_TP20R
TP_SWO: HECTOR_WATCH_1_TPTP20R; HECTOR_WATCH_1_TP20R
TP_VREG: HECTOR_WATCH_1_TPTP20R; HECTOR_WATCH_1_TP20R
U1: NRF52840_QF; NORDIC_NRF_4_AQFN50P700X700X85_HS-74N
X1: 32MHz; NORDIC_NRF_BT-XTAL_2016_N
X2: 32.768kHz; NORDIC_NRF_1_XTAL_3215_N

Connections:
3V3/2.4A: C6.1, C7.1, C8.1, C12.1, C14.1, C19.1, C25.1, C33.1, IC3.3 (VDDIO), IC3.7 (VDD), IC3.10 (CSB), IC9.E2 (VOUT_1), IC9.E3 (VOUT_2), J2.1, R17.1, R18.1, TP_3.3V.TP, TP_3V3.TP, U1.P$A22 (VDD), U1.P$AD14 (VDD), U1.P$AD23 (VDD), U1.P$B1 (VDD), U1.P$W1 (VDD), U1.P$Y2 (VDDH)
ALERT/2.5C: U1.P$J24 (P0.10/NFC2)
D+/2.7D: U1.P$AD6 (D+)
D-/2.7D: U1.P$AD4 (D-)
DEC3: C11.1, U1.P$D23 (DEC3)
DEC4_6: C10.1, C15.1, C16.1, L3.2, U1.P$B5 (DEC4), U1.P$E24 (DEC6)
EPD_BUSY/2.2D: U1.P$AD12 (P0.17)
EPD_CS/2.2D: U1.P$K2 (P0.05/AIN3)
EPD_DC/2.2: U1.P$AD10 (P0.15)
EPD_RST/2.2D: U1.P$AC11 (P0.16)
GND: C1.2, C2.2, C3.2, C4.2, C5.2, C6.2, C7.2, C8.2, C9.2, C10.2, C11.2, C12.2, C13.2, C14.2, C15.2, C16.2, C17.1, C18.1, C19.2, C20.2, C21.2, C22.2, C23.1, C24.1, C25.2, C33.2, C37.2, C38.2, C39.2, IC1.D2 (GND), IC3.8 (GNDIO), IC3.9 (GND), IC9.B1 (VSEL), IC9.C1 (AGND), IC9.C2 (PGND_1), IC9.C3 (PGND_2), J2.3, J2.5, R3.1, R9.1, TP_GND.TP, U1.P$74 (VSS_PAD), U1.P$75 (VSS_PAD), U1.P$76 (VSS_PAD), U1.P$77 (VSS_PAD), U1.P$78 (VSS_PAD), U1.P$79 (VSS_PAD), U1.P$80 (VSS_PAD), U1.P$81 (VSS_PAD), U1.P$82 (VSS_PAD), U1.P$83 (VSS_PAD), U1.P$84 (VSS_PAD), U1.P$85 (VSS_PAD), U1.P$86 (VSS_PAD), U1.P$87 (VSS_PAD), U1.P$88 (VSS_PAD), U1.P$89 (VSS_PAD), U1.P$90 (VSS_PAD), U1.P$B7 (VSS), U1.P$F23 (VSS_PA), X1.2, X1.4; also elsewhere on the board
HAPTIC_EN/2.6A: U1.P$U1 (P0.12)
IMU_INT1: IC3.5 (INT1), U1.P$N1 (P0.08)
IMU_INT2: IC3.6 (INT2), U1.P$P2 (P1.08)
LX1: IC9.B2 (SW1_1), IC9.B3 (SW1_2), L7.1
LX2: IC9.D2 (SW2_1), IC9.D3 (SW2_2), L7.2
MOSI/2.2D: U1.P$B13 (P0.03/AIN1)
unnamed: C5.1, U1.P$C1 (DEC1)
unnamed: L2.1, U1.P$B3 (DCC)
unnamed: IC1.D1 (TS/MR), R9.2
unnamed: IC9.D1 (SCL), R4.2
unnamed: C3.1, L1.1, U1.P$H23 (ANT)
unnamed: IC9.E1 (SDA), R2.2
unnamed: C1.1, U1.P$B24 (XC1), X1.1
unnamed: C2.1, U1.P$A23 (XC2), X1.3
unnamed: C20.1, U1.P$AC5 (DEC3V3)
unnamed: IC3.1 (SDO), R3.2
unnamed: L2.2, L3.1
unnamed: C9.1, U1.P$N24 (DEC5)
unnamed: C13.1, U1.P$A18 (DEC2)
P0.00/XL1: C17.2, U1.P$D2 (P0.00/XL1), X2.1
P0.01/XL2: C18.2, U1.P$F2 (P0.01/XL2), X2.2
P0.04: U1.P$J1 (P0.04/AIN2)
P0.09: U1.P$L24 (P0.09/NFC1)
P0.13/2.6C: U1.P$AD8 (P0.13)
P0.14/2,7C: U1.P$AC9 (P0.14)
P0.19: U1.P$AC15 (P0.19)
P0.20: U1.P$AD16 (P0.20)
P0.21: U1.P$AC17 (P0.21)
P0.22: U1.P$AD18 (P0.22)
P0.23: U1.P$AC19 (P0.23)
P0.24: U1.P$AD20 (P0.24)
P0.25: U1.P$AC21 (P0.25)
P0.26: U1.P$G1 (P0.26)
P0.27: U1.P$H2 (P0.27)
P0.28: U1.P$B11 (P0.28/AIN4)
P0.29: U1.P$A10 (P0.29/AIN5)
P0.30: U1.P$B9 (P0.30/AIN6)
P0.31: U1.P$A8 (P0.31/AIN7)
P1.01/2.4B: U1.P$Y23 (P1.01)
P1.02/2.8C: U1.P$W24 (P1.02)
P1.03: U1.P$V23 (P1.03)
P1.04: U1.P$U24 (P1.04)
P1.05: U1.P$T23 (P1.05)
P1.06: U1.P$R24 (P1.06)
P1.07: U1.P$P23 (P1.07)
P1.09: U1.P$R1 (P1.09)
P1.10: U1.P$A20 (P1.10)
P1.11: U1.P$B19 (P1.11)
P1.12: U1.P$B17 (P1.12)
P1.13: U1.P$A16 (P1.13)
P1.14: U1.P$B15 (P1.14)
P1.15: U1.P$A14 (P1.15)
PMIC_INT: IC1.A1 (!INT), U1.P$T2 (P0.11)
RESET: J2.6, TP_RESET.TP, U1.P$AC13 (P0.18/RESET)
RF: ANT1.1 (FEED), C4.1, C22.1, L1.2
SCK/2.2D: U1.P$A12 (P0.02/AIN0)
SCL/2.4C: IC1.B1 (SCL), IC3.12 (SCX), R4.1, R17.2, TP_SCL.TP, U1.P$M2 (P0.07)
SDA/2.4C: IC1.C1 (SDA), IC3.2 (SDX), R2.1, R18.2, TP_SDA.TP, U1.P$L1 (P0.06)
SWDCLK: J2.4, TP_SWDCLK.TP, U1.P$AA24 (SWDCLK)
SWDIO: J2.2, TP_SWDIO.TP, U1.P$AC24 (SWDIO)
SWO: TP_SWO.TP, U1.P$AD22 (P1.00)
VBAT/2.5C: C37.1, IC1.C2 (BAT)
VBUS/2.6D: C21.1, C38.1, IC1.A2 (IN), U1.P$AD2 (VBUS)
VREG: C23.2, C24.2, C39.1, IC1.B2 (SYS), IC9.A1 (EN), IC9.A2 (VIN_1), IC9.A3 (VIN_2), TP_VREG.TP

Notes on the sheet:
LiPo Charger
DC/DC
IMU
SWD

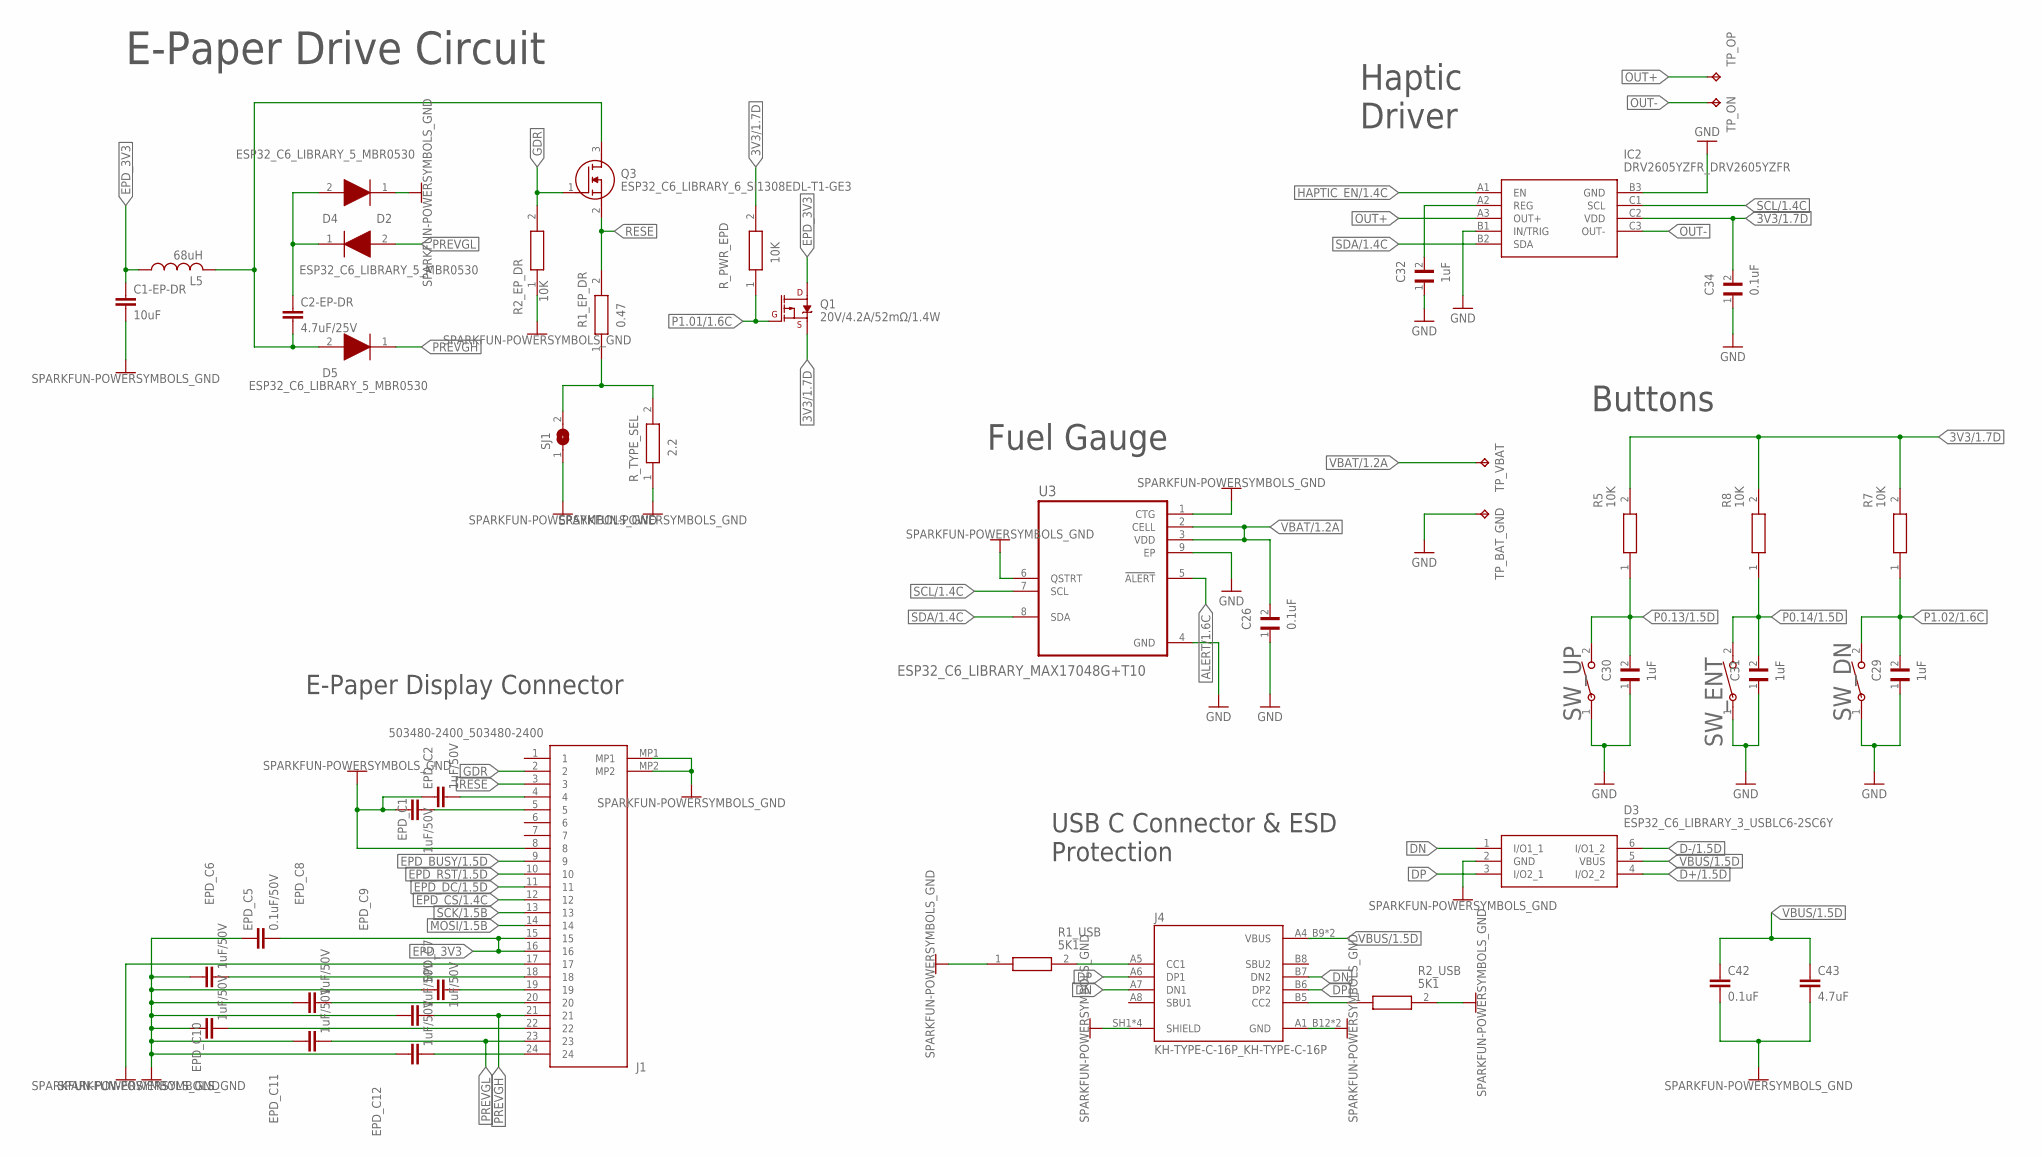
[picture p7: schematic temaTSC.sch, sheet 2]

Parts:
C1-EP-DR: 10uF; NORDIC_NRF_3_RESC0402_L
C2-EP-DR: 4.7uF/25V; NORDIC_NRF_3_RESC0402_L
C26, C34: 0.1uF; GRM011R60J152KE01L_1_0201
C29, C30, C31, C32: 1uF; GRM011R60J152KE01L_1_0201
C42: 0.1uF; NORDIC_NRF_3_RESC0201_L
C43: 4.7uF; NORDIC_NRF_3_RESC0402_L
D2, D4, D5: ESP32_C6_LIBRARY_5_MBR0530; ESP32_C6_LIBRARY_5_SOD3716X135N
D3: ESP32_C6_LIBRARY_3_USBLC6-2SC6Y; ESP32_C6_LIBRARY_3_SOT95P280X145-6N
EPD_C1, EPD_C2, EPD_C6, EPD_C7, EPD_C8, EPD_C9, EPD_C10, EPD_C11, EPD_C12: 1uF/50V; NORDIC_NRF_3_RESC0402_L
EPD_C5: 0.1uF/50V; NORDIC_NRF_3_RESC0201_L
IC2: DRV2605YZFR_DRV2605YZFR; DRV2605YZFR_BGA9C50P3X3_144X144X62
J1: 503480-2400_503480-2400; 503480-2400_5034802400
J4: KH-TYPE-C-16P_KH-TYPE-C-16P; KH-TYPE-C-16P_KINGHELM_KH-TYPE-C-16P
L5: 68uH; NORDIC_NRF_2_RESC0402_L
Q1: 20V/4.2A/52mΩ/1.4W; ESP32_C6_LIBRARY_4_ESP32_C6_LIBRARY_4_ESP32_C6_LIBRARY_4_ES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
Q3: ESP32_C6_LIBRARY_6_SI1308EDL-T1-GE3; ESP32_C6_LIBRARY_6_SOT65P210X110-3N
R1_EP_DR: 0.47; ERA-1AEB3401C_0201
R1_USB, R2_USB: 5K1; ERA-1AEB3401C_0201
R2_EP_DR, R5, R7, R8: 10K; ERA-1AEB3401C_0201
R_PWR_EPD: 10K; ERA-1AEB3401C_0201
R_TYPE_SEL: 2.2; ERA-1AEB3401C_0201
SJ1: ESP32_C6_LIBRARY_7_JUMPER_SJ
SW_DN: 2025-10-22_07-23-44_LIBRARY_EVP-AKE31ASW_EVP-AKE3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; 2025-10-22_07-23-44_LIBRARY_SW_EVP-AKE31A_PAN
SW_ENT: 2025-10-22_07-23-44_LIBRARY_EVP-AKE31ASW_EVP-AKE3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; 2025-10-22_07-23-44_LIBRARY_SW_EVP-AKE31A_PAN
SW_UP: 2025-10-22_07-23-44_LIBRARY_EVP-AKE31ASW_EVP-AKE3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; 2025-10-22_07-23-44_LIBRARY_SW_EVP-AKE31A_PAN
TP_BAT_GND: HECTOR_WATCH_1_TPTP20R; HECTOR_WATCH_1_TP20R
TP_ON: HECTOR_WATCH_1_TPTP20R; HECTOR_WATCH_1_TP20R
TP_OP: HECTOR_WATCH_1_TPTP20R; HECTOR_WATCH_1_TP20R
TP_VBAT: HECTOR_WATCH_1_TPTP20R; HECTOR_WATCH_1_TP20R
U3: ESP32_C6_LIBRARY_MAX17048G+T10; ESP32_C6_LIBRARY_SON50P200X200X80-9N

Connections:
3V3/1.7D: C34.2, IC2.C2 (VDD), Q1.2 (S), R5.2, R7.2, R8.2, R_PWR_EPD.2
ALERT/1.6C: U3.5 (!ALERT)
D+/1.5D: D3.4 (I/O2_2)
D-/1.5D: D3.6 (I/O1_2)
DN: D3.1 (I/O1_1), J4.A7 (DN1), J4.B7 (DN2)
DP: D3.3 (I/O2_1), J4.A6 (DP1), J4.B6 (DP2)
EPD_3V3: C1-EP-DR.1, EPD_C5.2, J1.15, J1.16, L5.1, Q1.3 (D)
EPD_BUSY/1.5D: J1.9
EPD_CS/1.4C: J1.12
EPD_DC/1.5D: J1.11
EPD_RST/1.5D: J1.10
GDR: J1.2, Q3.1 (G), R2_EP_DR.2
GND: C1-EP-DR.2, C26.1, C29.1, C30.1, C31.1, C32.1, C34.1, C42.2, C43.2, D3.2 (GND), D4.1 (K), EPD_C1.1, EPD_C2.1, EPD_C5.1, EPD_C6.1, EPD_C7.1, EPD_C8.1, EPD_C9.1, EPD_C10.1, EPD_C11.1, EPD_C12.1, IC2.B1 (IN/TRIG), IC2.B3 (GND), J1.8, J1.17, J1.MP1, J1.MP2, J4.A1_B12 (GND), J4.A12_B1 (GND), J4.SH1 (SHIELD), J4.SH2 (SHIELD), J4.SH3 (SHIELD), J4.SH4 (SHIELD), R1_USB.1, R2_EP_DR.1, R2_USB.2, R_TYPE_SEL.1, SJ1.1, SW_DN.1, SW_ENT.1, SW_UP.1, TP_BAT_GND.TP, U3.1 (CTG), U3.4 (GND), U3.6 (QSTRT), U3.9 (EP); also elsewhere on the board
HAPTIC_EN/1.4C: IC2.A1 (EN)
MOSI/1.5B: J1.14
unnamed: C2-EP-DR.2, D5.2 (A), L5.2, Q3.3 (D)
unnamed: EPD_C6.2, J1.18
unnamed: C2-EP-DR.1, D2.1 (K), D4.2 (A)
unnamed: EPD_C7.2, J1.19
unnamed: EPD_C2.2, J1.4
unnamed: EPD_C1.2, J1.5
unnamed: EPD_C8.2, J1.20
unnamed: R1_EP_DR.1, R_TYPE_SEL.2, SJ1.2
unnamed: EPD_C10.2, J1.22
unnamed: EPD_C12.2, J1.24
unnamed: J4.B5 (CC2), R2_USB.1
unnamed: C32.2, IC2.A2 (REG)
unnamed: J4.A5 (CC1), R1_USB.2
OUT+: IC2.A3 (OUT+), TP_OP.TP
OUT-: IC2.C3 (OUT-), TP_ON.TP
P0.13/1.5D: C30.2, R5.1, SW_UP.2
P0.14/1.5D: C31.2, R8.1, SW_ENT.2
P1.01/1.6C: Q1.1 (G), R_PWR_EPD.1
P1.02/1.6C: C29.2, R7.1, SW_DN.2
PREVGH: D5.1 (K), EPD_C9.2, J1.21
PREVGL: D2.2 (A), EPD_C11.2, J1.23
RESE: J1.3, Q3.2 (S), R1_EP_DR.2
SCK/1.5B: J1.13
SCL/1.4C: IC2.C1 (SCL), U3.7 (SCL)
SDA/1.4C: IC2.B2 (SDA), U3.8 (SDA)
VBAT/1.2A: C26.2, TP_VBAT.TP, U3.2 (CELL), U3.3 (VDD)
VBUS/1.5D: C42.1, C43.1, D3.5 (VBUS), J4.A4_B9 (VBUS), J4.A9_B4 (VBUS)

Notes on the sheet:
E-Paper Drive Circuit
Haptic Driver
Buttons
Fuel Gauge
E-Paper Display Connector
USB C Connector & ESD Protection

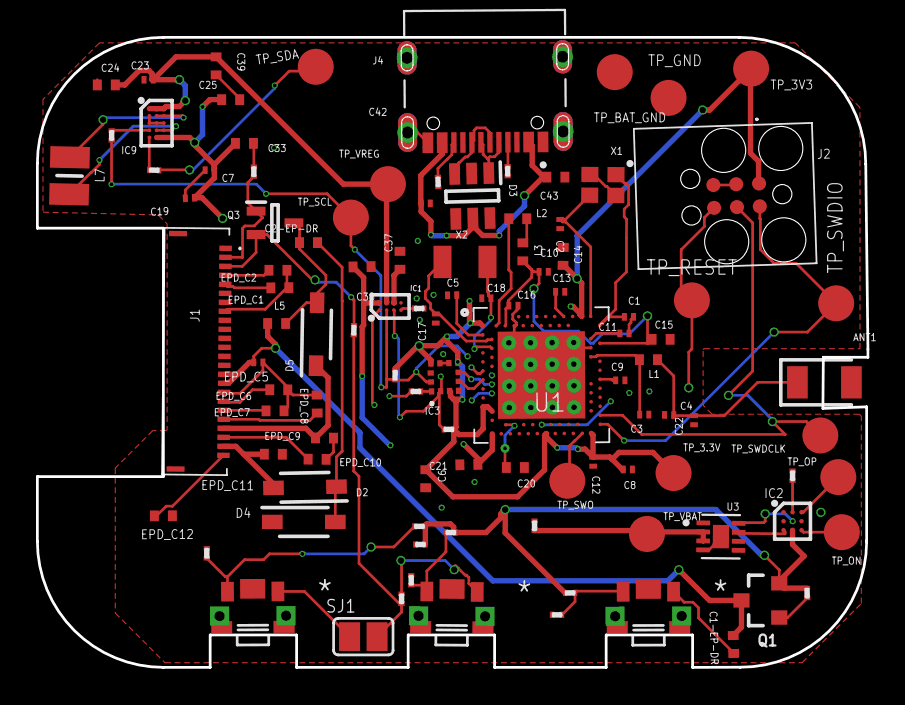
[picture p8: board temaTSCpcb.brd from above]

Board: 4 copper layers, 46.1 x 35.0 mm, 105 parts (0 on the bottom side), 65 nets.

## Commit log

2026-04-16 improvement for error details
    Updated the design log section with detailed explanations of various approved errors and overlaps encountered during PCB design, including specific types and their implications for functionality and manufacturing.
2026-04-16 Fix datasheet link for BLE antenna
    Updated the datasheet link for the BLE antenna.
2026-04-16 schematic dupa review
    [temaTSC.sch]
2026-04-16 pcb dupa review
    [temaTSCpcb.brd]

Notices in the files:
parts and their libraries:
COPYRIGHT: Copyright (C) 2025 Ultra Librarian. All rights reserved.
